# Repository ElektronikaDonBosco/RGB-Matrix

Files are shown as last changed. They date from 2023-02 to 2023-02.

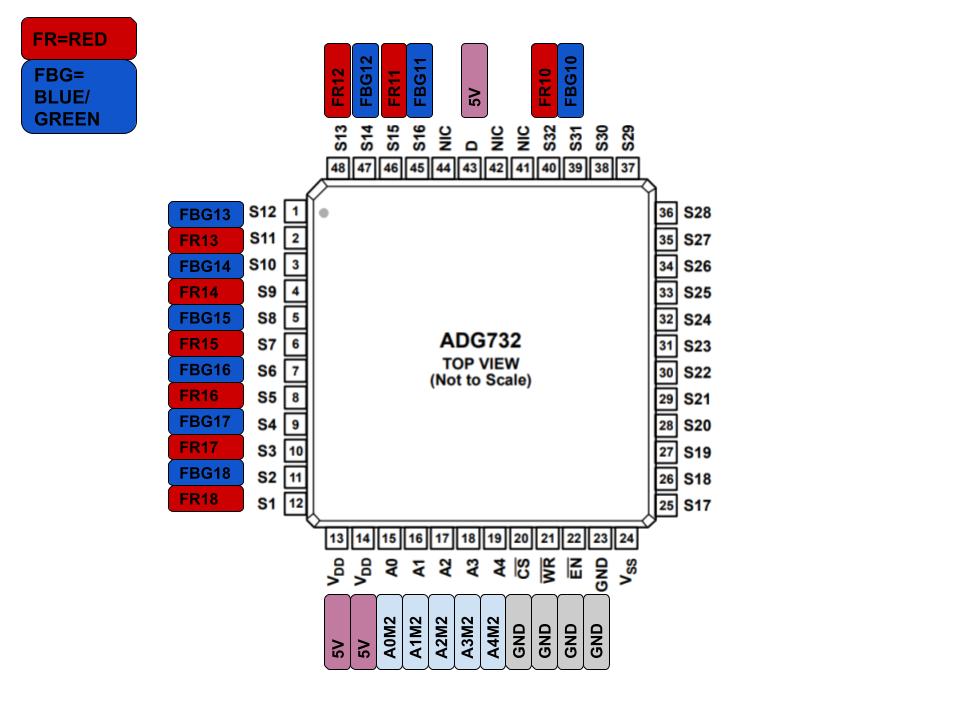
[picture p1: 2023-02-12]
PROYECT/Teensy pin out/multiplex fbg.jpg

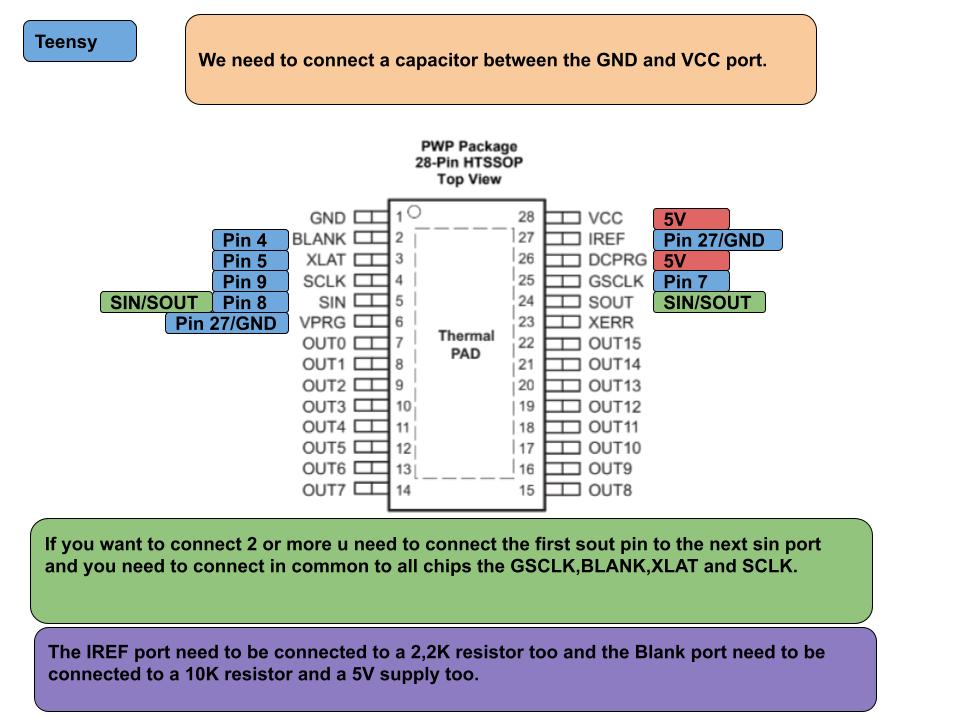
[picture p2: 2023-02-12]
PROYECT/Teensy pin out/Driver.jpg

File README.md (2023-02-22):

# RGB-Matrix-proyect
We dont create the libraries we use for this proyect give the support to the real creators.

https://github.com/PaulStoffregen/Tlc5940

https://github.com/pfeerick/elapsedMillis

In the first step we need to know the list of raw material:
576x Leds RGB WP154A4SEJ3VBDZGW/CA
6x Drivers TLC 5940 PWP (needed to control the colors and brightness)
2x Multiplexor ADG732 (to give tension to the anodes of every roW of led)
36x SMD resistor of 1K 
2x resistor 10K
6x resistor 2.2K
1x resistor 1.5K
1x resistor 2.5K
1x resistor 250
6x capacitor 1uF
36x Transistor 2STX2220 X2220 TO92 
1x Power supply 230V to 5V 1,5A
1x Teensy 4.0
1x NRF2401 (we use this device to receive the data from the camara)
2x LM317 (2 voltage divider to get a tension of 4.29V and a 3.7V)
2x Potentiometer of 1.5K
2x 80 pin strip

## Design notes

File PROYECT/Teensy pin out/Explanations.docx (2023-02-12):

The RGB leds have this tension specifications

We have a 5V power supply so we need to add 2 voltage divider (LM317)

1º of 4,3Vmax - 1,9Vmin with a potentiometer of 10K and a resistor of 260

2º of 3,7Vmax - 1,3Vmin with a potentiometer of 2,5K and a resistor of 1.5K

With the second power supply we have a maximum voltage rate of 3,7V but we need to adjust the potentiometer to give a maximum of 3,6V because we have the NRF2401.

—------------------------------------------------------------------------------------------------------------------------

The NRF2401 have a maximum voltage of 3,6V. We use this device to receive the information from the master Teensy and send it to our Teensy to create the program.

(The NRF2401 connections to the Teensy are on image 1 )

—------------------------------------------------------------------------------------------------------------------------

To control the brightness and the color of the leds we use 6 TLC5940 DRIVER because we need to control 3 colors and we have 32 leds row that make 96 ports and every DRIVER have 15 ports.We have to connect every connection to a GND.

The connections to the the Teensy are in image 1

The pinn out of the driver are in image 2

—------------------------------------------------------------------------------------------------------------------------

We don't have enough ports in the Teensy that's why we use 2 Multiplexor ADG 732 1º for the red colors and the 2º for the blue and green colors.we control every row anode and put the supply in this point.

The connections to the Teensy are in image 1

The pin out of the multiplexor for first half are in image 3

The pin out of the multiplexor for second half are in image 4

IMAGE 1

Datasheet:

https://www.pjrc.com/store/teensy40.html

IMAGE 2

Datasheet:

IMAGE 3

IMAGE 4

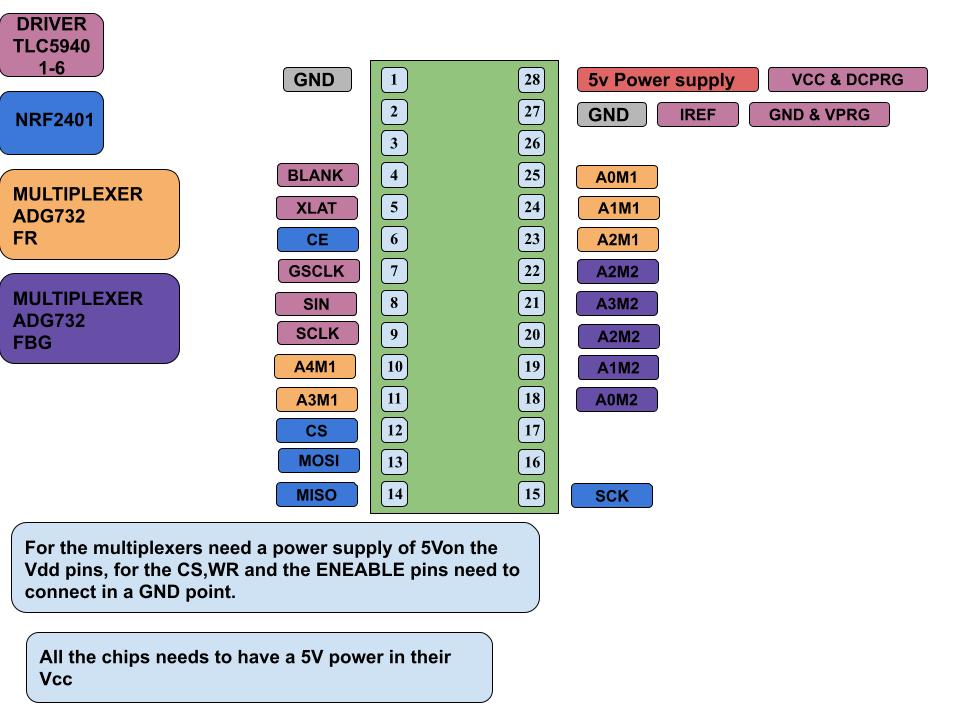
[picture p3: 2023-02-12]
PROYECT/Teensy pin out/Teensy.jpg

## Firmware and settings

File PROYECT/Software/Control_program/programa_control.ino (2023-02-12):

//los pines que sean.
#include "Tlc5940.h"
int mux1[5]= {23,22,21,9,8};
int mux2[5]= {20,19,18,17,16};


//linea off
int lineOFF=21;

//lineas multiplex1. Están ordenados por línea y R, luego BG: 1R, 1BG, 2R, 2BG...
int linesMux1R[9]={5,9,13,30,14,10,6,2,0};
int linesMux1GB[9]={3,7,11,15,31,12,8,4,1};

//lineas multiplex2. Están ordenados por línea y R, luego BG: 10R, 10BG, 11R, 11BG...
int linesMux2R[9]={31,14,12,10,8,6,4,1,0};
int linesMux2GB[9]={30,15,13,11,9,7,5,3,2};

// canales
int Red1=0;
int Green1=1;
int Blue1=2;




void setup() {
  Serial.begin(9600);
  Tlc.init();
  //inicializa los pines 0
  for (int x = 0; x < 5; x++) {
    pinMode(mux1[x], OUTPUT);
    digitalWrite(mux1[x], LOW);
  }
   for (int x = 0; x < 5; x++) {
    pinMode(mux2[x], OUTPUT);
    digitalWrite(mux2[x], LOW);
  }


switchOff();
delay(1000);
lineSelect(mux1,linesMux1R[0]);
Tlc.set(Red1,3000);
Tlc.update();
//lineSelect(mux2, lineOFF);
//delay(1000);
//switchOff();

  
//  for (int x = 1; x<9; x++){
//      lineSelect(mux1,linesMux1R[x]);
//      delay(10);
//      //lineSelect(mux1, lineOFF);
//    }
//    lineSelect(mux1, lineOFF);
//    
//    for (int x = 0; x<9; x++){
//      lineSelect(mux2,linesMux2R[x]);
//      delay(100);
//    }
//    lineSelect(mux2, lineOFF);
//        
//        for (int x = 0; x<9; x++){
//      lineSelect(mux1,linesMux1GB[x]);
//      delay(100);
//    }
//    lineSelect(mux1, lineOFF);
//    
//  for (int x = 0; x<9; x++){
//      lineSelect(mux2,linesMux2GB[x]);
//      delay(100);
//    }
//    lineSelect(mux2, lineOFF);
//  Tlc.set(R1,3000);
//  Tlc.update();
// lineSelect(mux1,linesMux1R[0]);


}

void loop() {
//  lineSelect(mux2, lineOFF);
//  Tlc.set(R1,300);
//  Tlc.update();
// lineSelect(mux1,linesMux1R[0]);
// delayMicroseconds(100);
// lineSelect(mux1, lineOFF);
// lineSelect(mux2, lineOFF);
//  Tlc.set(Blue1,300);
//  Tlc.update();
// lineSelect(mux1,linesMux1R[0]);
// delayMicroseconds(100);
// lineSelect(mux1, lineOFF);
// lineSelect(mux2, lineOFF);
//  Tlc.set(G1,3000);
//  Tlc.update();
// lineSelect(mux1,linesMux1R[0]);
// delayMicroseconds(100);
// lineSelect(mux1, lineOFF);
// lineSelect(mux2, lineOFF);
  // put your main code here, to run repeatedly:
// for (int x = 1; x<9; x++){
//      lineSelect(mux1,linesMux1R[x]);
//      delay(10);
//      pintarlinea();
//      //lineSelect(mux1, lineOFF);
//    }
//    lineSelect(mux1, lineOFF);
//    
//    for (int x = 0; x<9; x++){
//      lineSelect(mux2,linesMux2R[x]);
//      delay(100);
//      pintarlinea();
//    }
//    lineSelect(mux2, lineOFF);
//        
//        for (int x = 0; x<9; x++){
//      lineSelect(mux1,linesMux1GB[x]);
//      delay(100);
//      pintarlinea();
//    }
//    lineSelect(mux1, lineOFF);
//    
//  for (int x = 0; x<9; x++){
//      lineSelect(mux2,linesMux2GB[x]);
//      delay(100);
//      pintarlinea();
//    }
//    lineSelect(mux2, lineOFF);
// 
// 
//  
}

/*COMENTARIO QUÉ REALIZA ESTA FUNCIÓN*/
void lineSelect(int mux[], int pinnum){
  for (int x = 0; x<5; x++){
      byte state = bitRead(pinnum, x);
      digitalWrite(mux[x], state); 
}
}

/*COMENTARIO QUÉ REALIZA ESTA FUNCIÓN*/
void switchOff (){
lineSelect(mux1, lineOFF);
lineSelect(mux2, lineOFF);
Tlc.clear();
Tlc.update();
  }

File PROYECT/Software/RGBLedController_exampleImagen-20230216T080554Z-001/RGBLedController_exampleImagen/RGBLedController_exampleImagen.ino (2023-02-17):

//Librerias
#include "Tlc5940.h"
#include <Bounce.h>
#include <elapsedMillis.h>
//variable tiempo espera


//Salidas del Teensy que controlan los dos multiplexores (A0,A1,A2,A3,A4)
int mux1[5] = {23,22,21,9,8};
int mux2[5] = {20,19,18,17,16};

//ADG732 enables
int enable1 = 15;
int enable2 = 14;

//linea off
int lineOFF = 21;

//TLC5940 maxímos pasos en la escala de grises (son 4096 niveles, de 0 a 4095)
int maxSteps = 4095;

//Los leds tendrán una resolución de 8 bits, es decir, de 0 a 255 niveles
int maxResolution = 255;

//lineas multiplex1. Están ordenados por línea y R, luego BG: 1R, 1BG, 2R, 2BG...9R, 9BG
int linesMux1R[9] = {5,9,13,30,14,10,6,2,0};
int linesMux1GB[9] = {3,7,11,15,31,12,8,4,1};

//lineas multiplex2. Están ordenados por línea y R, luego BG: 10R, 10BG, 11R, 11BG...18R,18-bg
int linesMux2R[9] = {31,14,12,10,8,6,4,1,0};
int linesMux2GB[9] = {30,15,13,11,9,7,5,3,2};

// Canales. Hay 6 drivers en cascada. Cada uno de 16 entradas/salidas. Se numeran:0,1,2 red, green, blue sucesivamente
int ledRed[32] = {0,3,6,9,12,15,18,21,24,27,30,33,36,39,42,45,48,51,54,57,60,63,66,69,72,75,78,81,84,87,90,93};
int ledGreen[32] = {1,4,7,10,13,16,19,22,25,28,31,34,37,40,43,46,49,52,55,58,61,64,67,70,73,76,79,82,85,88,91,94};
int ledBlue[32] = {2,5,8,11,14,17,20,23,26,29,32,35,38,41,44,47,50,53,56,59,62,65,68,71,74,77,80,83,86,89,92,95};


//delay time
int delaySeconds = 10;
int delayMicros = 1;


//IMAGEN CREADA EN PAINT.  
byte red [18][32] = {
{0, 0, 237, 237, 237, 237, 237, 237, 0, 0, 0, 0, 0, 0, 0, 0, 0, 0, 0, 0, 0, 0, 0, 0, 0, 0, 0, 0, 0, 0, 0, 0},
{0, 0, 237, 237, 237, 237, 237, 237, 0, 0, 0, 0, 0, 0, 0, 0, 0, 0, 0, 0, 0, 0, 0, 0, 0, 0, 0, 0, 0, 0, 0, 0},
{0, 0, 237, 237, 237, 237, 237, 237, 0, 0, 0, 0, 0, 0, 0, 0, 0, 0, 0, 0, 0, 0, 0, 0, 0, 0, 0, 0, 0, 0, 0, 0},
{0, 0, 237, 237, 237, 237, 237, 237, 0, 0, 0, 0, 0, 0, 0, 0, 0, 34, 34, 34, 34, 34, 34, 0, 0, 0, 0, 0, 0, 0, 0, 0},
{0, 0, 237, 237, 237, 237, 237, 237, 0, 0, 0, 0, 0, 0, 0, 0, 0, 34, 34, 34, 34, 34, 34, 0, 0, 0, 0, 0, 0, 0, 0, 0},
{0, 0, 237, 237, 237, 237, 237, 237, 0, 0, 0, 0, 0, 0, 0, 0, 0, 34, 34, 34, 34, 34, 34, 0, 0, 0, 0, 0, 0, 0, 0, 0},
{0, 0, 0, 0, 0, 0, 0, 0, 0, 0, 0, 0, 0, 0, 0, 0, 0, 34, 34, 34, 34, 34, 34, 0, 0, 0, 0, 0, 0, 0, 0, 0},
{0, 0, 0, 0, 0, 0, 63, 63, 63, 63, 63, 63, 63, 0, 0, 0, 0, 34, 34, 34, 34, 34, 34, 0, 0, 0, 0, 0, 0, 0, 0, 0},
{0, 0, 0, 0, 0, 0, 63, 63, 63, 63, 63, 63, 63, 0, 0, 0, 0, 34, 34, 34, 34, 34, 34, 0, 0, 0, 0, 0, 0, 0, 0, 0},
{0, 0, 0, 0, 0, 0, 63, 63, 63, 63, 63, 63, 63, 0, 0, 0, 0, 34, 34, 34, 34, 34, 34, 0, 0, 0, 0, 0, 0, 0, 0, 0},
{0, 0, 0, 0, 0, 0, 63, 63, 63, 63, 63, 63, 63, 0, 0, 0, 0, 0, 0, 0, 0, 0, 0, 0, 0, 0, 0, 0, 0, 0, 0, 0},
{0, 0, 0, 0, 0, 0, 63, 63, 63, 63, 63, 63, 63, 0, 0, 0, 0, 0, 0, 0, 0, 0, 0, 0, 0, 0, 0, 0, 0, 0, 0, 0},
{0, 0, 0, 0, 0, 0, 63, 63, 63, 63, 63, 63, 63, 0, 0, 0, 0, 0, 0, 0, 0, 0, 0, 0, 0, 0, 0, 0, 0, 0, 0, 0},
{0, 0, 0, 0, 0, 0, 63, 63, 63, 63, 63, 63, 63, 0, 0, 0, 0, 0, 0, 0, 0, 0, 0, 0, 0, 0, 0, 0, 0, 0, 0, 0},
{0, 0, 0, 0, 0, 0, 63, 63, 63, 63, 63, 63, 63, 0, 0, 0, 0, 0, 0, 0, 0, 0, 0, 0, 0, 0, 0, 0, 0, 0, 0, 0},
{0, 0, 0, 0, 0, 0, 0, 0, 0, 0, 0, 0, 0, 0, 0, 0, 0, 0, 0, 0, 0, 0, 0, 0, 0, 0, 0, 0, 0, 0, 0, 0},
{0, 0, 0, 0, 0, 0, 0, 0, 0, 0, 0, 0, 0, 0, 0, 0, 0, 0, 0, 0, 0, 0, 0, 0, 0, 0, 0, 0, 0, 0, 0, 0},
{0, 0, 0, 0, 0, 0, 0, 0, 0, 0, 0, 0, 0, 0, 0, 0, 0, 0, 0, 0, 0, 0, 0, 0, 0, 0, 0, 0, 0, 0, 0, 0}
};
byte green [18][32] = {
{0, 0, 28, 28, 28, 28, 28, 28, 0, 0, 0, 0, 0, 0, 0, 0, 0, 0, 0, 0, 0, 0, 0, 0, 0, 0, 0, 0, 0, 0, 0, 0},
{0, 0, 28, 28, 28, 28, 28, 28, 0, 0, 0, 0, 0, 0, 0, 0, 0, 0, 0, 0, 0, 0, 0, 0, 0, 0, 0, 0, 0, 0, 0, 0},
{0, 0, 28, 28, 28, 28, 28, 28, 0, 0, 0, 0, 0, 0, 0, 0, 0, 0, 0, 0, 0, 0, 0, 0, 0, 0, 0, 0, 0, 0, 0, 0},
{0, 0, 28, 28, 28, 28, 28, 28, 0, 0, 0, 0, 0, 0, 0, 0, 0, 177, 177, 177, 177, 177, 177, 0, 0, 0, 0, 0, 0, 0, 0, 0},
{0, 0, 28, 28, 28, 28, 28, 28, 0, 0, 0, 0, 0, 0, 0, 0, 0, 177, 177, 177, 177, 177, 177, 0, 0, 0, 0, 0, 0, 0, 0, 0},
{0, 0, 28, 28, 28, 28, 28, 28, 0, 0, 0, 0, 0, 0, 0, 0, 0, 177, 177, 177, 177, 177, 177, 0, 0, 0, 0, 0, 0, 0, 0, 0},
{0, 0, 0, 0, 0, 0, 0, 0, 0, 0, 0, 0, 0, 0, 0, 0, 0, 177, 177, 177, 177, 177, 177, 0, 0, 0, 0, 0, 0, 0, 0, 0},
{0, 0, 0, 0, 0, 0, 72, 72, 72, 72, 72, 72, 72, 0, 0, 0, 0, 177, 177, 177, 177, 177, 177, 0, 0, 0, 0, 0, 0, 0, 0, 0},
{0, 0, 0, 0, 0, 0, 72, 72, 72, 72, 72, 72, 72, 0, 0, 0, 0, 177, 177, 177, 177, 177, 177, 0, 0, 0, 0, 0, 0, 0, 0, 0},
{0, 0, 0, 0, 0, 0, 72, 72, 72, 72, 72, 72, 72, 0, 0, 0, 0, 177, 177, 177, 177, 177, 177, 0, 0, 0, 0, 0, 0, 0, 0, 0},
{0, 0, 0, 0, 0, 0, 72, 72, 72, 72, 72, 72, 72, 0, 0, 0, 0, 0, 0, 0, 0, 0, 0, 0, 0, 0, 0, 0, 0, 0, 0, 0},
{0, 0, 0, 0, 0, 0, 72, 72, 72, 72, 72, 72, 72, 0, 0, 0, 0, 0, 0, 0, 0, 0, 0, 0, 0, 0, 0, 0, 0, 0, 0, 0},
{0, 0, 0, 0, 0, 0, 72, 72, 72, 72, 72, 72, 72, 0, 0, 0, 0, 0, 0, 0, 0, 0, 0, 0, 0, 0, 0, 0, 0, 0, 0, 0},
{0, 0, 0, 0, 0, 0, 72, 72, 72, 72, 72, 72, 72, 0, 0, 0, 0, 0, 0, 0, 0, 0, 0, 0, 0, 0, 0, 0, 0, 0, 0, 0},
{0, 0, 0, 0, 0, 0, 72, 72, 72, 72, 72, 72, 72, 0, 0, 0, 0, 0, 0, 0, 0, 0, 0, 0, 0, 0, 0, 0, 0, 0, 0, 0},
{0, 0, 0, 0, 0, 0, 0, 0, 0, 0, 0, 0, 0, 0, 0, 0, 0, 0, 0, 0, 0, 0, 0, 0, 0, 0, 0, 0, 0, 0, 0, 0},
{0, 0, 0, 0, 0, 0, 0, 0, 0, 0, 0, 0, 0, 0, 0, 0, 0, 0, 0, 0, 0, 0, 0, 0, 0, 0, 0, 0, 0, 0, 0, 0},
{0, 0, 0, 0, 0, 0, 0, 0, 0, 0, 0, 0, 0, 0, 0, 0, 0, 0, 0, 0, 0, 0, 0, 0, 0, 0, 0, 0, 0, 0, 0, 0},
};
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
